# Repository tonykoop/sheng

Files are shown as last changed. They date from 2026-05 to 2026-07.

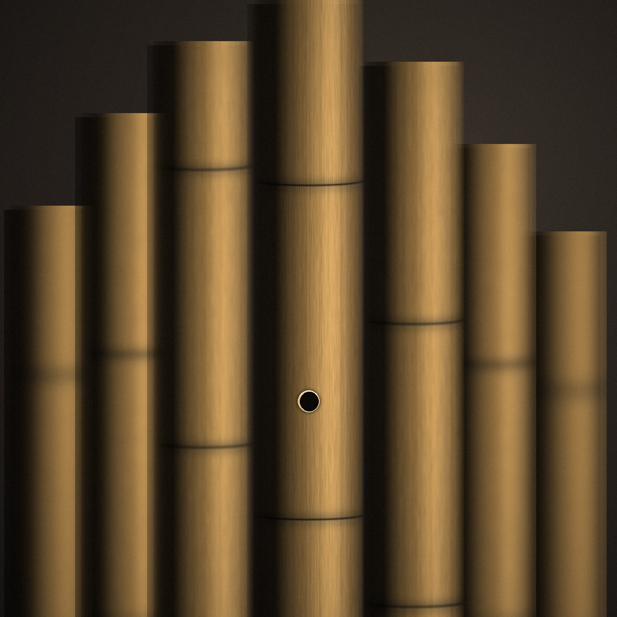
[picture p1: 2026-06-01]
images/macro/pipe-bundle-finger-holes.png

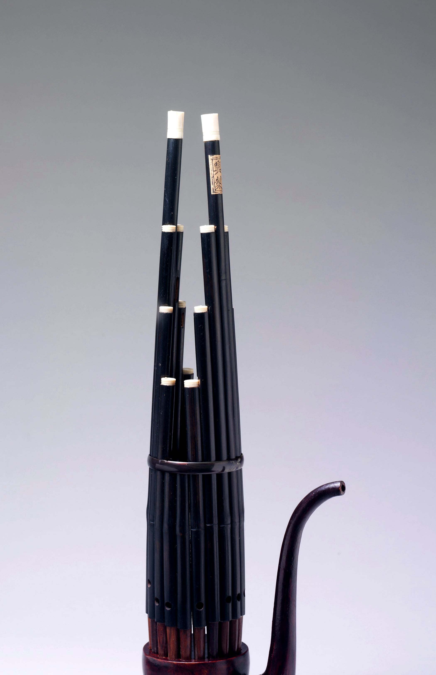
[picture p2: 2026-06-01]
images/hero-render.png

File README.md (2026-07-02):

# Sheng Mouth-Organ Family Packet

Generated: 2026-05-10

Status: L2 V5 build-packet candidate.

Current status: scaffold packet with two explicit architecture variants.
Fabrication authority: not build-ready.
Wolfram/runtime status: source-only; no Wolfram runtime validation has been run.

Studio explorer: open `explorer.html` for a generated packet showcase that
summarizes the design files, branch choices, validation gates, print packet,
Wolfram starter, and current public-release blockers.

This packet promotes the Round 8 sheng split from issue #153 and the
`tonykoop/sheng` issue #1 starter packet without choosing a premature winner.
The first workflow decision is the architecture branch:

- `traditional-side-branch/` keeps the traditional sheng-like side-branch reed
  model with both pipe ends open.
- `compact-control/` keeps the compact stopped-end prototype model with the
  reed acting as the closed end.

The two `family-spec.csv` files are intentionally separate. Do not merge them
into one universal sheng sheet unless measured reed coupon and single-pipe
control data prove that the same acoustic law and boundary condition apply to
both layouts.

## Quick Start

1. Read `architecture-choice.md` and pick exactly one branch for the next shop
   action.
2. Use `traditional-side-branch/family-spec.csv` when preserving a traditional
   sheng-like long-pipe geometry is the first design goal.
3. Use `compact-control/family-spec.csv` when proving a short, serviceable
   reed-pipe module is the first design goal.
4. Follow `free-reed-empirical-loop.md` and fill `p0-reed-coupon-log.csv`
   before claiming final reed pitch, onset pressure, pull-down, or cut-ready
   socket geometry.
5. Fill `p1-single-pipe-control-log.csv` and `windchest-geometry-plan.csv`
   before claiming coupled pipe pitch, chamber leakage status, or branch
   promotion beyond L2.
6. Check `safety-gates.csv` before any reed cutting, pressure test, leak test,
   or full-body layout.
7. Run the v4.4 acoustic-law validator on the chosen branch and the visual
   authority validator on `visual-output-register.csv`.

## File Map

| File | Purpose |
| --- | --- |
| `design.md` | Shared intent, scope, unknowns, and validation gates. |
| `architecture-choice.md` | First decision point: traditional side-branch vs compact control. |
| `traditional-side-branch/family-spec.csv` | Validator-aligned side-branch reed rows. |
| `compact-control/family-spec.csv` | Validator-aligned closed-open compact rows. |
| `p0-reed-coupon-log.csv` | Required reed coupon worksheet before full-family claims. |
| `p0-reed-coupon-data-sheet.csv` | Detailed P0 geometry and safety-source template for each coupon candidate. |
| `p1-single-pipe-control-log.csv` | Required coupled reed-pipe worksheet before branch promotion. |
| `free-reed-empirical-loop.md` | P0/P1 bench protocol with pull-down, onset, leak, and stop gates. |
| `windchest-geometry-plan.csv` | Chamber, gasket, inlet, pressure tap, and service-access planning table. |
| `safety-gates.csv` | Safety gates that must pass before cutting, pressure testing, or layout promotion. |
| `p0-onset-capture-form.csv` | P0 onset capture form for initial free-reed performance checks. |
| `p0-pull-down-capture-form.csv` | P0 pull-down capture form for target-pitch response checks. |
| `mouth-organ-dxf-checklist.csv` | Future DXF/CAD authority checklist. |
| `visual-output-register.csv` | V5 authority register for visuals, print packet, and concept support. |
| `cad/` | V5 CAD/provenance starter folder; not fabrication authority yet. |
| `wolfram/` | Source-only Wolfram model (`sheng-wolfram-model.wl`); not executed. |
| `evolution/` | Stage 0 evolution-pipeline intake (design intent, revision register, master manifest); Gate A not yet run. |
| `validation.csv` | Gates that move each branch from scaffold to prototype evidence. |

Both branch family specs carry `acoustic_law`, `end_condition`,
`reed_source_role`, and `unknown_requires_measurement` as explicit table
columns. The measurement gate is intentionally still open: no row claims final
reed dimensions, pull-down behavior, tuning measurements, or build-ready
windchest geometry.

## Round 33C Measurement Loop Evidence

Issue #8 adds single-pass bench-fill rows for both active P0 reed coupons and
one compact-control P1 single-pipe row. These rows record source role,
reed-alone pitch, pull-down/onset behavior, coupled pitch, response notes, and
leak/service observations, but they remain measurement-loop evidence only.
Repeat measurements and reviewed CAD/DXF or design-table authority are still
required before any branch promotion, production geometry, or public-readiness
claim.

## Validation Command

```bash
python3 /home/tony/.codex/skills/instrument-maker-v4/scripts/validate_acoustic_law.py \
  docs/build-packets/sheng-mouth-organ-family/traditional-side-branch/family-spec.csv

python3 /home/tony/.codex/skills/instrument-maker-v4/scripts/validate_acoustic_law.py \
  docs/build-packets/sheng-mouth-organ-family/compact-control/family-spec.csv
```

For this root-mode repo, run the same validator against the local files:

```bash
python3 /home/tony/.codex/skills/instrument-maker/scripts/validate_acoustic_law.py \
  traditional-side-branch/family-spec.csv

python3 /home/tony/.codex/skills/instrument-maker/scripts/validate_acoustic_law.py \
  compact-control/family-spec.csv

python3 /home/tony/.codex/skills/instrument-maker/scripts/validate_visual_authority.py \
  visual-output-register.csv
```

`Status: L2 V5 build-packet candidate` means the packet has the reviewable V5
surface and named blockers. It does not mean the sheng is build-ready.

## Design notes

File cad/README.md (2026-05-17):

# Sheng CAD Starter

Status: L2 V5 build-packet candidate support only.

This folder exists to anchor V5 CAD/provenance work without implying that
fabrication geometry is ready.

Current authority:

- `p0-p1-control-parameters.csv` is a design-table starter for review and
  measurement planning.
- `mcp-session-log.md` records the provenance and authority class of source
  artifacts.

Current non-authority:

- No DXF is cut-ready.
- No CAD body, windchest, reed window, socket map, or gasket land is
  fabrication authority.
- No Wolfram output has been executed or exported as runtime evidence.

Promotion beyond L2 requires measured P0 reed coupon data, measured P1
single-pipe control data, and reviewed DXF/CAD/design-table authority for the
chosen branch.

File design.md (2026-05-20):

# Sheng Traditional and Compact Prototype Packet

Generated: 2026-05-10

Issues addressed: tonykoop/instrument-maker#153; tonykoop/sheng#1.
V5 readiness: L2 V5 build-packet candidate, not L3/L4.
V5 standard source: tonykoop/instrument-maker#186.
MCP provenance source: tonykoop/instrument-maker#188.

## Scope

This packet publishes two sheng prototype branches as separate, validator-ready
packet variants:

- Traditional side-branch sheng: `acoustic_law=side_branch_reed`,
  `end_condition=both_ends_open`.
- Compact stopped-end prototype: `acoustic_law=closed_open`,
  `end_condition=one_end_closed_reed`.

Both branches are scaffold-level design packets. They are not build-ready CAD,
DXF, reed plates, or sourcing instructions. The pipe-length rows are first-pass
physics rows for branch comparison and validator alignment; reed behavior still
requires measured coupons and a single-pipe control before any full mouth-organ
layout can be treated as fabrication authority.

Each branch `family-spec.csv` now carries the Round 30 free-reed guard fields:
`acoustic_law`, `end_condition`, `reed_source_role`, and
`unknown_requires_measurement`. The two physics rows remain branch-comparison
scaffolds only; those explicit fields prevent a half-wave side-branch sheng row
from being confused with a compact closed-open control row, and they keep donor
reed or handmade reed behavior measurement-required until P0/P1 evidence is
logged.

## Architecture Decision First

Before drafting a body, windchest, or pipe rack, choose one branch in
`architecture-choice.md`.

Choose `traditional-side-branch` when the design objective is a traditional
sheng-like architecture: long pipes, reed in a side wall or socket area, and
both pipe ends acoustically open.

Choose `compact-control` when the design objective is a smaller experimental
module: a short pipe or chamber where the reed/windchest side creates the
closed boundary and the pipe speaks as a closed-open resonator.

Do not mix rows across branches in one fabrication drawing. The same target
note has different predicted pipe length in the two sheets because the boundary
condition is different.

## Fabrication Authority

Current fabrication authority: not build-ready.

Future authority must come from one of:

- Measured reed coupon data in `p0-reed-coupon-log.csv`.
- A single-pipe control drawing and measurement log.
- DXF/CAD files that name the governing branch, reed window, socket map, gasket
  land, service access, and pipe length source.
- A reviewed design table or measured template tied to the chosen branch.

Generated images, concept sketches, or visual-BOM plates may support review but
must not become dimensional authority for reed windows, pipe length, socket
location, or windchest geometry.

V5 packet authority is recorded in `visual-output-register.csv` and
`cad/mcp-session-log.md`. Current rows are source scaffolds and reference-only
outputs; none of them upgrades the packet beyond L2.

## P0/P1 Validation Plan

P0 is reed-alone evidence. Use `p0-reed-coupon-data-sheet.csv` to
record reed source, material, geometry, and fixture/safety pre-checks, and
`p0-reed-coupon-log.csv` to record reed-alone pitch, onset pressure, pull-down
target, blow/draw behavior, gap, window size, gasket leak status, and
measurement environment.

Collect free-reed behavior with dedicated capture forms before any P1 gate claim:
- `p0-pull-down-capture-form.csv`
- `p0-onset-capture-form.csv`

P1 is coupled reed-pipe evidence. Use `p1-single-pipe-control-log.csv` to record
one traditional side-branch single pipe and one compact closed-open control
before choosing a full-family body layout. P1 rows must cite their P0 coupon ID
and report coupled pitch error; blank P1 rows block any L3 or build-ready claim.

`free-reed-empirical-loop.md` is the bench protocol for both phases. It keeps
the test order explicit: source and inspect the reed, fixture it mechanically,
measure reed-alone pitch and onset, test pull-down behavior, then move the same
coupon into one single-pipe control only after safety and leakage gates pass.

`windchest-geometry-plan.csv` is a planning table, not fabrication geometry. It
names chamber volume, pressure path, gasket land, pressure tap, inlet, service
direction, and leak-test evidence that a future DXF or CAD file must carry.

Round 33C adds issue #8 measurement-loop rows for two P0 coupon candidates and
one compact-control P1 single-pipe control. Treat those rows as single-pass
bench evidence: useful for traceability and next-test planning, but still
repeat-required before branch promotion, production reed geometry, DXF/CAD
authority, or public-readiness claims.

## Open Measurements

| Measurement | Why It Matters | Status |
| --- | --- | --- |
| Reed-alone pitch for candidate sheng or donor reeds | Determines pull-down and whether target rows are realistic | measurement-required |
| Onset pressure and blow/draw behavior | Determines playability and windchest pressure range | measurement-required |
| Reed tongue gap and window geometry | Controls response, choking, and leakage | measurement-required |
| Gasket leak rate and service access | Controls repeatability and repairability | measurement-required |
| Single-pipe coupled pitch | Confirms the selected acoustic law before family layout | measurement-required |
| Windchest chamber leak behavior | Separates reed instability from fixture leakage | measurement-required |
| Safe pressure limit and reed retention | Prevents loose reed parts or overpressure during tests | measurement-required |

## Branch Promotion Gates

Move a branch from scaffold to prototype only when:

- Its `family-spec.csv` passes the v4.4 acoustic-law validator.
- At least one P0 reed coupon has measured reed-alone pitch, onset behavior,
  blow/draw behavior, leak status, and gap setting.
- One single-pipe control has a measured coupled pitch and notes whether it
  matches the declared acoustic law.
- The DXF/CAD checklist identifies branch, end condition, reed window, socket
  map, gasket land, windchest section, and service direction.
- The windchest plan records chamber volume, pressure tap, inlet, gasket land,
  leak-test method, leak status, and service access for the chosen branch.
- `safety-gates.csv` has no open stop conditions for the phase being promoted.
- `visual-output-register.csv` keeps generated or concept visuals out of the
  fabrication authority chain.
- `cad/mcp-session-log.md` names any external CAD/creative/runtime tool output
  and marks Wolfram work as source-only unless execution evidence exists.

## Safety and Scope Gates

- Do not claim current supplier availability, price, or lead time without a
  fresh purchase-time check.
- Do not publish private family/media/archive contents.
- Do not treat branch-comparison pipe lengths as cut-ready dimensions.
- Do not collapse the two branch family specs into one fake universal answer.

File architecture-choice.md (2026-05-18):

# Sheng Architecture Choice

Pick this before layout, CAD, DXF, sourcing, or full pipe count.

## Branch Comparison

| Branch | Use When | Acoustic Law | End Condition | Reed Source Role | Measurement Gate |
| --- | --- | --- | --- | --- | --- |
| `traditional-side-branch` | Preserve traditional sheng-like long pipes and side-branch reed coupling. | `side_branch_reed` | `both_ends_open` | `side_branch_free_reed_controls_pipe_coupling` | `unknown_requires_measurement` until P0 coupon and P1 side-branch pipe data exist. |
| `compact-control` | Prove a shorter, serviceable prototype module before committing to a traditional body. | `closed_open` | `one_end_closed_reed` | `free_reed_forms_closed_end_boundary` | `unknown_requires_measurement` until P0 coupon and P1 closed-open pipe data exist. |

## Traditional Side-Branch

Choose this branch when the primary value is architectural fidelity: long
visible pipes, a mouth-organ windchest, and a reed coupled through a side branch
or socket while both pipe ends remain acoustically open.

This branch uses half-wave pipe lengths in
`traditional-side-branch/family-spec.csv`. It is longer and less compact, but
it preserves the traditional boundary-condition claim that issue #153 asks us
to keep alive. The branch family spec names the reed role explicitly as
`side_branch_free_reed_controls_pipe_coupling` and keeps the measurement gate
open until P0/P1 evidence exists.

## Compact Control

Choose this branch when the primary value is fast empirical learning: a smaller
pipe module, easier reed service, and a clearer path to coupon-to-pipe
iteration.

This branch uses quarter-wave pipe lengths in
`compact-control/family-spec.csv`. It should not be described as traditional
sheng geometry; it is a compact prototype branch for proving reed, gasket,
socket, and windchest behavior. The branch family spec names the reed role
explicitly as `free_reed_forms_closed_end_boundary` and keeps the measurement
gate open until P0/P1 evidence exists.

## Shared Unknowns

Both branches need the same evidence before becoming build-ready:

- Reed-alone pitch.
- Coupled single-pipe pitch.
- Onset pressure.
- Pull-down cents.
- Blow/draw response.
- Leak status.
- Serviceable reed plate and gasket geometry.

If those measurements are missing, keep the branch label as scaffold or
prototype-planning, not production-ready.

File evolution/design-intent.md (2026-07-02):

# Design Intent — sheng rev A

- Master CAD: `cad/sheng.scad` (sha256: 695142b5c0cb4ef439ee537e12c7555de688d43d194713c1f1f25c70422e50e9), envelope-only pipe-rank master driven by `traditional-side-branch/family-spec.csv` (sha256: b47adbbefbd0d1ecc64dc0abc944b9fe332aedd9946f84c5a092b5edc4d9c62f) and `compact-control/family-spec.csv` (sha256: 59520daadd1f13a5ab16e09da1f7fe91ae88ca3afb64b3034391aa04bb44c8d8).
- Function: A free-reed mouth-organ (sheng), published as two comparable architecture branches rather than one premature winner (`architecture-choice.md`). `traditional-side-branch` preserves traditional sheng-like long pipes with the reed coupled through a side branch or socket while both pipe ends stay acoustically open (`acoustic_law=side_branch_reed`, `end_condition=both_ends_open`, half-wave pipe law). `compact-control` is a smaller experimental module where the reed/windchest side forms the closed boundary and the pipe speaks as a closed-open resonator (`acoustic_law=closed_open`, `end_condition=one_end_closed_reed`, quarter-wave pipe law). Both branches share the same eight-note rank (D4-E4-G4-A4-C5-D5-E5-G5) for direct comparison.
- Environment: bench/shop prototype; reed behavior (onset pressure, pull-down, blow/draw) is pressure- and leak-sensitive, so P0 (reed-alone) and P1 (single-pipe coupled) bench evidence must precede any full-family or windchest claim (`free-reed-empirical-loop.md`).
- Target qty: 1 (prototype). Deadline: TBD. Budget/unit ceiling: TBD.

## Critical dimensions (carry tolerances)

| Feature | Nominal | Tolerance | Why critical | Source |
| --- | --- | --- | --- | --- |
| Traditional-branch pipe rank lengths (D4-G5) | 575.9 / 512.2 / 429.4 / 381.6 / 319.6 / 283.9 / 252.0 / 210.6 mm | verify against measured coupled pitch (P1) | half-wave pipe length sets pitch under `side_branch_reed` law | traditional-side-branch/family-spec.csv `predicted_L_geom_mm` (physics_derived, analysis_only) |
| Compact-branch pipe rank lengths (D4-G5) | 287.9 / 256.1 / 214.7 / 190.8 / 159.8 / 141.9 / 126.0 / 105.3 mm | verify against measured coupled pitch (P1) | quarter-wave pipe length sets pitch under `closed_open` law | compact-control/family-spec.csv `predicted_L_geom_mm` (physics_derived, analysis_only) |
| Reed window size, tongue gap | TBD | measurement_required | controls response, choking, leakage; directly governs whether pull-down targets are realistic | cad/p0-p1-control-parameters.csv CAD-P0-001 / CAD-P0-002; `unknown_requires_measurement` — reed gate stays OPEN |
| Coupled pitch error (per branch) | TBD | measurement_required | confirms the declared acoustic law before any family layout | cad/p0-p1-control-parameters.csv CAD-P1-004; p1-single-pipe-control-log.csv |
| Windchest chamber volume, pressure tap, gasket land | TBD | measurement_required | separates reed instability from chamber leakage; sets serviceability | windchest-geometry-plan.csv; cad/p0-p1-control-parameters.csv CAD-WC-001..004 |
| Safe pressure limit | TBD (below onset overpressure) | measurement_required, safety-critical | prevents reed plate ejection / loose parts during testing | safety-gates.csv SAFE-003, SAFE-004 |

## Incidental (free for DFM)

- Windchest exterior styling, mouthpiece cosmetic shaping, pipe rank visual arrangement/fan angle, non-mating surface finish.

## Must-nots (DFM may never violate)

- Do not treat branch-comparison pipe lengths as cut-ready dimensions (design.md "Safety and Scope Gates"; risks.md "Fabrication").
- Do not collapse the two branch family-spec tables into one universal sheet — the boundary condition differs (`architecture-choice.md`).
- Do not infer reed window, tongue gap, or gasket land from concept images or generated visuals (cad/p0-p1-control-parameters.csv notes; safety-gates.csv SAFE-007).
- Do not exceed the logged safe pressure limit during onset/leak testing; reed plate must be mechanically retained before any pressure test (safety-gates.csv SAFE-002, SAFE-003; risks.md "Safety").
- Do not build a full mouth-organ windchest/body layout before one branch has measured coupled pitch, onset behavior, leak status, and service-access evidence (free-reed-empirical-loop.md P1 step 3).

## Material intent

- Preferred: bamboo or hardwood for traditional-side-branch long pipes; hardwood or printed test core for compact-control short control pipes (per branch `family-spec.csv` `material` column and bom.csv BOM-002/BOM-003).
- Acceptable subs: substitution_candidate status per bom.csv (BOM-002 through BOM-005); not yet coupon-tested.
- Forbidden: none recorded.

## Stage status

Stage 0 intake complete 2026-07-01. Gate A (Alpha shop compile) NOT yet run — no concessions logged, nothing presented as shippable. Reed/reed-table geometry, windchest chamber, and voicing remain unmeasured (`unknown_requires_measurement`) and out of scope for the current CAD master.

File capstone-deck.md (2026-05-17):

# Project Intent

Publish the sheng split from issue #153 and the `tonykoop/sheng` issue #1
starter packet as two explicit packet variants without forcing a premature
architecture winner.

# Branch Decision

The first decision is `traditional-side-branch` versus `compact-control`.

# Traditional Branch

Traditional side-branch rows use `side_branch_reed` with
`end_condition=both_ends_open`.

# Compact Branch

Compact control rows use `closed_open` with
`end_condition=one_end_closed_reed`.

# Family Spec

Each branch has its own `family-spec.csv`. The sheets must stay separate unless
measurements prove a shared acoustic model.

# Coupon Gate

The P0 reed coupon records reed-alone pitch, onset pressure, blow/draw behavior,
gap, window size, pull-down behavior, retention, and leak status.

# Single-Pipe Gate

One measured single-pipe control comes before any full mouth-organ body layout.

# Windchest Gate

Chamber volume, pressure tap, gasket land, inlet, service access, and leak
method stay in planning tables until measured evidence exists.

# Drawing Authority

Future DXF/CAD must name branch, reed window, socket map, gasket land,
windchest section, and service direction.

# Visual Authority

Generated images are concept or reference support only.

# Fabrication Status

Current status is scaffold. This packet is not build-ready.

# Risks

The primary risks are unmeasured reed behavior, chamber leakage, unsafe
pressure testing, and accidental branch mixing.

# Next Actions

Pick a branch, fill the P0 coupon and safety gates, build one single-pipe
control, run chamber leak checks, then revise the selected branch sheet with
measured evidence.

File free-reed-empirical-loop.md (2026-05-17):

# Free-Reed P0/P1 Empirical Loop

Status: L2 validation protocol. This is not build-ready fabrication geometry.

Use this loop before promoting either sheng branch beyond scaffold status. The
same coupon ID must follow the evidence chain from reed-alone testing into one
single-pipe control so branch behavior is traceable.

## P0 Reed Coupon

1. Source and identify the reed.
   Record `reed_source`, `source_status`, `source_provenance`, material, tongue
   length, tongue width, thickness, window length, window width, and frame land
   width in `p0-reed-coupon-log.csv`.
2. Inspect and make safe.
   Deburr all cut metal, confirm the reed plate is mechanically retained, and
   set a conservative pressure limit before blowing or using shop air.
3. Measure reed-alone pitch.
   Use a tuner or frequency logger while sweeping pressure slowly. Record the
   stable pitch range and the measurement environment.
4. Measure onset.
   Use a manometer or pressure sensor and record the first repeatable speaking
   pressure. If the reed starts only at unsafe pressure, stop and mark the
   coupon blocked.
5. Measure pull-down.
   Test whether the reed can be pulled toward the target note without choking,
   buzz instability, or unsafe pressure. Record target cents and measured cents.
6. Check leakage.
   Run a low-pressure hold on the coupon fixture. Leakage must be separated
   from reed instability before the coupon is allowed into P1.

## P1 Single-Pipe Control

1. Choose exactly one branch.
   Use `traditional-side-branch` for the side-branch reed model or
   `compact-control` for the closed-open control model.
2. Copy the P0 coupon ID into `p1-single-pipe-control-log.csv`.
   Do not create anonymous P1 rows.
3. Build only the single-pipe control.
   Full-family body layout waits until one branch has measured coupled pitch,
   onset behavior, leak status, and service-access evidence.
4. Record windchest geometry planning data.
   Fill `windchest-geometry-plan.csv` for chamber ID, chamber volume, inlet,
   pressure tap, gasket land, service direction, and leak-test method.
5. Measure coupled behavior.
   Record pitch, pitch error in cents, onset pressure, blow/draw behavior,
   chamber leak status, and service-access result.
6. Promote or revise.
   If coupled pitch or onset contradicts the declared acoustic law, keep the
   branch at L2 and revise the family-spec rows before any DXF/CAD authority.

## Stop Conditions

- Reed plate shifts, lifts, or ejects during pressure testing.
- Sharp reed tongue or burr remains after inspection.
- Onset requires pressure above the logged safe limit.
- Leak test cannot distinguish chamber leakage from reed response.
- The P1 row lacks a traceable P0 coupon ID.
- A drawing or generated image is being treated as dimensional authority before
  measured coupon and single-pipe data exist.

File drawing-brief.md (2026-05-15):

# Sheng Drawing Brief

Current drawing status: future authority.

## Required Drawings

| Drawing | Branch | Authority Level | Must Prove |
| --- | --- | --- | --- |
| P0 reed coupon DXF | both | future fabrication authority | Reed window, clamp line, tongue travel direction, gasket land |
| Traditional single-pipe control | traditional-side-branch | future fabrication authority | Side-branch reed placement and both-ends-open pipe condition |
| Compact single-pipe control | compact-control | future fabrication authority | Reed-side closed boundary and one open pipe end |
| Windchest section | both | future fabrication authority | Pressure path, service access, gasket compression, chamber assumption |
| Socket pitch map | selected branch only | future fabrication authority | Pipe ID, reed ID, note, acoustic law, length source |

## Non-Authority Visuals

Concept images and visual-BOM plates may communicate layout intent. They must
not set pipe length, reed window size, socket center, toolpath, or gasket
geometry.

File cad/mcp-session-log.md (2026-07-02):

# MCP Session Log

V5 provenance — aligned with `tonykoop/instrument-maker` V5 build-packet standard.

No MCP-connected CAD tool, image generator, or Wolfram runtime has produced
fabrication authority for this packet. All rows below are design-table derivations
or measurement-template work; none carry fabrication authority.

| session_id | tool | input_authority | outputs | role | authority_result | review_status | notes |
| --- | --- | --- | --- | --- | --- | --- | --- |
| 2026-05-17-design-table-v1 | design-table | acoustic-law formulas | traditional-side-branch/family-spec.csv | cad_authoring | reference_only | self_checked | Physics-derived branch rows; L2 only; not build-ready. |
| 2026-05-17-design-table-v1 | design-table | acoustic-law formulas | compact-control/family-spec.csv | cad_authoring | reference_only | self_checked | Physics-derived branch rows; L2 only; not build-ready. |
| 2026-05-17-design-table-v2 | design-table | p0-reed-coupon-log.csv | cad/p0-p1-control-parameters.csv | cad_authoring | reference_only | unreviewed | CAD parameter starter derived from coupon log; measurements TBD. |
| 2026-05-17-wolfram-v1 | wolfram | cad/p0-p1-control-parameters.csv | sheng-starter.wl | cad_authoring | reference_only | unreviewed | Source-only starter; not executed. |
| 2026-05-17-design-table-v3 | design-table | p1-single-pipe-control-log.csv | windchest-geometry-plan.csv | cad_authoring | reference_only | unreviewed | Windchest planning fields only; no fabrication geometry. |
| 2026-05-17-measurement-template-v1 | measurement-template | free-reed-empirical-loop.md | safety-gates.csv | cad_authoring | reference_only | unreviewed | Safety gate checklist; open until bench evidence exists. |
| 2026-05-18-round30-v1 | design-table | cad/mcp-session-log.md | traditional-side-branch/family-spec.csv; compact-control/family-spec.csv | cad_authoring | reference_only | self_checked | Added explicit reed_source_role and unknown_requires_measurement guard fields; still L2 only. |
| 2026-05-29-bob-r1 | measurement-template | p0-reed-coupon-log.csv; p1-single-pipe-control-log.csv | docs/p0-p1-measurement-summary.md | cad_authoring | reference_only | self_checked | Consolidated Round 33C evidence summary; no fabrication authority added. |
| fable-v5-refresh-2026-07-01 | claude-code (Fable 5) | traditional-side-branch/family-spec.csv; compact-control/family-spec.csv | visual-output-register.csv | packet_refresh | fabrication | self_checked | V5 refresh pass; tabular packet data reviewed against design table. `authority_result=fabrication` describes this register row (V5 bookkeeping authority) only — no instrument CSV in this repo carries fabrication authority yet; reed gates stay open per design.md ("Current fabrication authority: not build-ready"). |
| fable-v5-refresh-2026-07-01 | claude-code (Fable 5) | traditional-side-branch/family-spec.csv; compact-control/family-spec.csv | cad/sheng.scad | cad_authoring | pending_measurement | self_checked | New envelope-only OpenSCAD master: models ONLY the pipe-rank envelope (length + rank position) for both branches from the exact predicted_L_geom_mm rows in each family-spec.csv. Reed/reed-table geometry, windchest chamber, and voicing stay out of scope (unmeasured per p0-p1-control-parameters.csv). Render check: `openscad -o /tmp/sheng-check.stl cad/sheng.scad` exit 0. |
| fable-v5-refresh-2026-07-01 | claude-code (Fable 5) | cad/p0-p1-control-parameters.csv | wolfram/sheng-wolfram-model.wl | analysis_source | derived_preview | unreviewed | source-only; generated via generate_wolfram_packet.py, renamed from wolfram/instrument-model.wl; not executed (no --execute). |

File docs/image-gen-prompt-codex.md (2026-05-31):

# Image Generation Prompt

Concept image only; not fabrication authority. Do not include cut-ready dimensions, hole locations, reed-window dimensions, or toolpaths.

## Hero Prompt

Photorealistic 3/4 studio product visualization of a sheng prototype family packet represented as two real physical review objects: one traditional side-branch free-reed mouth-organ concept with long vertical pipes rising from a compact windchest, and one smaller compact-control single-pipe module with a short pipe, serviceable reed/windchest side, gasket land, and pressure-test fittings. Use bamboo or light wood pipes with subtle metal reed-plate details where visible, a clean unfinished prototype windchest, no ornate claims of traditional authenticity, clean neutral background, soft directional studio lighting, high detail, 50mm lens look.

## In-Context Prompt

Photorealistic bench-test scene for the sheng packet: a traditional side-branch pipe cluster and compact control module staged on an acoustician's workbench with reed coupons, gasket material, a small pressure gauge, leak-test notes, and removable pipe sockets. Natural workshop light, careful experimental mood, and visual separation between the two architecture branches so they are not mistaken for one universal design.

## Detail / Macro Prompt

Macro photorealistic close-up of the sheng signature mechanism as a prototype: a free-reed coupon seated near a pipe socket, gasket land, service-access screws, and the edge of a windchest, with a second pipe blurred behind it. Show the reed area as measurement-required and review-stage, with crisp material texture and no cut-ready reed-window geometry.

## Negative / Avoid

No text, no watermarks, no brand logos, no extra limbs, anatomically plausible hands if shown, no fake antique decoration, no impossible reed path, no merged branch geometry, no dimensions, no socket map, no toolpaths.

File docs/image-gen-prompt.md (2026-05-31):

# Image-Gen Prompts

Concept image only; not fabrication authority. Do not include cut-ready dimensions, hole locations, or toolpaths.

These prompts depict the envisioned sheng-style free-reed mouth organ described in
`design.md` and the visual/drawing briefs. They are concept visualizations and must
not set pipe length, reed-window size, socket centers, or windchest geometry. The
design carries two architecture branches (a traditional long-pipe side-branch sheng
with both pipe ends open, and a compact stopped-end control module); the hero and
in-context views show the recognizable bundled-pipe mouth-organ silhouette without
committing to measured pipe lengths or reed dimensions.

## Hero Prompt

A finished concept render of a sheng-style Chinese free-reed mouth organ standing
upright as a single hand-held instrument: a tight circular bundle of slender vertical
bamboo-toned pipes of varied lengths rising from a rounded cup-shaped windchest at the
base, with a short curved blow/draw mouthpiece tube projecting from the side of the
windchest. The pipes are gathered close like a sheaf, each a smooth turned tube with a
small fingering hole near its lower end where it enters the chest; the windchest reads
as a sealed metal-and-wood cup that bundles the pipe feet together. Materials and finish
implied by the design: warm honey-toned bamboo or pale hardwood pipes, a darker
lacquered or brushed-metal windchest cup, subtle visible reed sockets where pipes meet
the chest. Realistic hand-scale cues (an instrument about the height of a forearm),
clean neutral light-gray studio background, soft directional studio light from upper
left, 3/4 product-photography angle, ~50mm lens, shallow falloff, high detail,
photorealistic, no text labels.

## In-Context Prompt

The same bundled-pipe sheng concept staged on a maker's workbench in a quiet instrument
workshop: held lightly upright in two hands as if about to be played, the curved
mouthpiece near the player's lips, soft window daylight raking across the pipe bundle.
Background shows out-of-focus shop storytelling — a tuning bench, hand tools, a coil of
gasket cord, wood shavings — establishing this as a prototype free-reed mouth organ in
development. Natural light, shallow depth of field with the pipe bundle in crisp focus,
warm honest tones, concept visualization only, no text or callouts.

## Detail Prompt

A macro close-up at the base of the sheng where the slender pipes plug into the rounded
windchest cup: the signature free-reed sockets and pipe feet, showing how each pipe
seats into its gasketed socket with a small free reed implied at the closed boundary,
and a single fingering hole on the nearest pipe wall. Emphasize materials and textures —
fine bamboo grain, the seam where pipe meets the lacquered chest, a hint of brass reed
plate in shadow — under raking sidelight that brings out turning marks and the gasket
land. High detail, photorealistic, shallow depth of field, no measurements, no callouts.

## Negative / Avoid

No text, logos, watermarks, or fake maker marks; no dimension lines, hole-spacing
callouts, tuning numbers, or fabrication specifications; no impossible mechanisms or
free reeds drawn as fantasy parts; anatomically plausible hands if a player is shown.

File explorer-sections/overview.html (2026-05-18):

# 01 - OverviewSheng Mouth-Organ Family Packet

This explorer is the studio-facing index for the sheng free-reed mouth-organ packet. It brings the current design narrative, BOM, branch-specific family specs, validation gates, Wolfram source starter, print packet, and provenance notes into one review surface.

Packet status

The repo remains an L2 V5 build-packet candidate. It preserves two explicit architecture variants and keeps fabrication authority blocked until measured reed-coupon evidence, single-pipe control evidence, and reviewed DXF/CAD/design-table artifacts exist for the selected branch.

Round 30 free-reed guard

Both family specs now expose acoustic_law, end_condition, reed_source_role, and unknown_requires_measurement directly in the table. The traditional branch keeps the side-branch free reed as a pipe-coupling source; the compact branch keeps the free reed as the closed-end boundary. Both remain measurement-required until P0/P1 evidence exists.

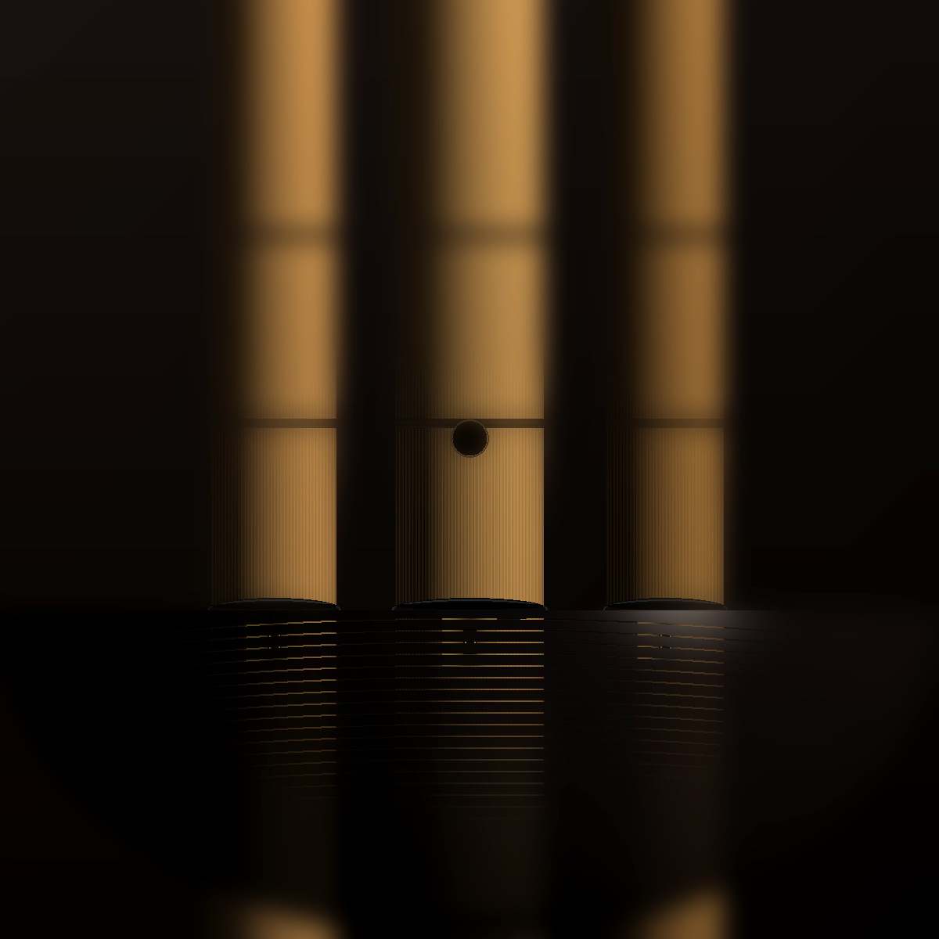
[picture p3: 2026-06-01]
images/macro/windchest-reed-sockets.png

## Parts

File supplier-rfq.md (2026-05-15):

# Sheng Prototype Supplier RFQ Notes

This is not a current quote request and does not claim price, availability, or
lead time.

## Quote Only After Measurements

Do not send an RFQ for a full branch until these rows exist:

- Reed-alone pitch.
- Onset pressure.
- Blow/draw behavior.
- Gap setting.
- Window size.
- Gasket leak status.
- One coupled single-pipe pitch.

## Candidate RFQ Fields

| Field | Required Detail |
| --- | --- |
| Branch | `traditional-side-branch` or `compact-control` |
| Reed material | Measured or specified alloy and thickness |
| Reed window | DXF/CAD authority file, not a concept image |
| Pipe material | Candidate material and bore/slot tolerance |
| Gasket | Material, compression stop, leak land |
| Service access | Direction and fastener access for reed replacement |

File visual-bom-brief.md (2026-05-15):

# Sheng Visual BOM Brief

Status: concept-support only.

## Visual Roles

| Visual | Role | Authority |
| --- | --- | --- |
| Branch comparison diagram | Explain side-branch vs compact-control decision | reference_only |
| Reed coupon photo or render | Show what to measure | reference_only until tied to measured coupon |
| Single-pipe control photo | Show test article | evidence_support after measurements are logged |
| Full sheng body concept | Communicate future direction | concept_only |

## Authority Rule

Any image generated by an AI model or drawn as a concept view must be labeled
`concept_only` or `reference_only`. Fabrication authority must remain DXF, CAD,
design table, measured template, or reviewed drawing.

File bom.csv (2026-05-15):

item_id | branch | item | qty | status | source_status | authority | notes
BOM-001 | both | free reed coupon blanks | 2 measurement sets | measurement-required | supplier_spec_unverified | not_fabrication_authority | Use only after reed-alone pitch and onset are measured
BOM-002 | traditional-side-branch | long pipe stock for side-branch control | 1 single-pipe test | measurement-required | substitution_candidate | not_fabrication_authority | Bamboo or hardwood candidate; final length comes after coupon validation
BOM-003 | compact-control | short control-pipe test core | 1 single-pipe test | measurement-required | substitution_candidate | not_fabrication_authority | Hardwood or printed test core for serviceable closed-open module
BOM-004 | both | gasket sheet and fasteners | 1 coupon set | measurement-required | supplier_spec_unverified | not_fabrication_authority | Choose after leak-land geometry is drawn
BOM-005 | both | windchest test block | 1 coupon fixture | measurement-required | substitution_candidate | not_fabrication_authority | Fixture for pressure path and service access experiments

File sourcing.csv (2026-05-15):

source_id | branch | component | source_status | search_terms | required_spec | notes
SRC-001 | both | sheng reed candidates | supplier_spec_unverified | sheng replacement reed brass free reed | reed material pitch window dimensions not yet measured | Verify at purchase time; no current price or availability claim
SRC-002 | compact-control | donor melodica reed candidates | supplier_spec_unverified | melodica reed plate donor replacement reeds | individual reed plate or salvageable donor reed | Use only as a coupon candidate until measured
SRC-003 | traditional-side-branch | bamboo or hardwood pipe stock | substitution_candidate | thin wall bamboo tube hardwood dowel bore blank | stable straight stock sized for single-pipe control | Stock dimensions are not authority for pipe length
SRC-004 | both | gasket material | supplier_spec_unverified | thin closed cell gasket sheet instrument reed plate | compressible leak-control gasket compatible with reed plate | Choose after gasket land and compression stop are drawn

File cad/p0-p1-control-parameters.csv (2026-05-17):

parameter_id | branch | phase | source_artifact | parameter | value | unit | status | authority | notes
CAD-P0-001 | both | P0 | p0-reed-coupon-log.csv | reed_window_size | TBD | mm | unknown_requires_measurement | measurement_required | Must come from measured reed or reviewed donor reed drawing
CAD-P0-002 | both | P0 | p0-reed-coupon-log.csv | tongue_gap | TBD | mm | unknown_requires_measurement | measurement_required | Do not infer from concept images
CAD-P0-003 | both | P0 | p0-reed-coupon-log.csv | gasket_leak_limit | TBD | TBD | unknown_requires_measurement | measurement_required | Define after coupon fixture leak test
CAD-P1-TRAD-001 | traditional-side-branch | P1 | traditional-side-branch/family-spec.csv | predicted_A4_pipe_length | 381.6 | mm | physics_derived | analysis_only | Half-wave side-branch row; not cut-ready until coupled pitch is measured
CAD-P1-COMP-001 | compact-control | P1 | compact-control/family-spec.csv | predicted_A4_pipe_length | 190.8 | mm | physics_derived | analysis_only | Quarter-wave compact row; not cut-ready until coupled pitch is measured
CAD-P1-004 | both | P1 | p1-single-pipe-control-log.csv | coupled_pitch_error | TBD | cents | unknown_requires_measurement | measurement_required | Required before branch promotion beyond L2
CAD-WC-001 | both | P1 | windchest-geometry-plan.csv | chamber_volume | TBD | ml | unknown_requires_measurement | measurement_required | Planning field only; must be measured or reviewed before CAD authority
CAD-WC-002 | both | P1 | windchest-geometry-plan.csv | pressure_tap_location | TBD | TBD | unknown_requires_measurement | measurement_required | Needed to separate onset pressure from chamber leakage
CAD-WC-003 | both | P1 | windchest-geometry-plan.csv | gasket_land_width | TBD | mm | unknown_requires_measurement | measurement_required | Do not infer from concept images or visual BOM
CAD-WC-004 | both | P1 | windchest-geometry-plan.csv | safe_pressure_limit | TBD | Pa | unknown_requires_measurement | measurement_required | Required safety gate before pressure tests

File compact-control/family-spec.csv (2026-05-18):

member_id | target_hz | target_note | architecture_branch | acoustic_law | end_condition | reed_source_role | unknown_requires_measurement | dimension_provenance | predicted_L_geom_mm | pipe_role | material | notes
SNG-COMP-D4 | 293.66 | D4 | compact-control | closed_open | one_end_closed_reed | free_reed_forms_closed_end_boundary | p0_reed_coupon_and_p1_single_pipe_required_before_fabrication | physics_derived | 287.9 | short_control_pipe | hardwood_or_printed_test_core | Quarter-wave compact branch; not traditional sheng geometry
SNG-COMP-E4 | 329.63 | E4 | compact-control | closed_open | one_end_closed_reed | free_reed_forms_closed_end_boundary | p0_reed_coupon_and_p1_single_pipe_required_before_fabrication | physics_derived | 256.1 | short_control_pipe | hardwood_or_printed_test_core | Quarter-wave compact branch; not traditional sheng geometry
SNG-COMP-G4 | 392.00 | G4 | compact-control | closed_open | one_end_closed_reed | free_reed_forms_closed_end_boundary | p0_reed_coupon_and_p1_single_pipe_required_before_fabrication | physics_derived | 214.7 | short_control_pipe | hardwood_or_printed_test_core | Quarter-wave compact branch; verify reed seat and gasket leak path
SNG-COMP-A4 | 440.00 | A4 | compact-control | closed_open | one_end_closed_reed | free_reed_forms_closed_end_boundary | p0_reed_coupon_and_p1_single_pipe_required_before_fabrication | physics_derived | 190.8 | short_control_pipe | hardwood_or_printed_test_core | A440 compact anchor candidate; coupon data required before layout
SNG-COMP-C5 | 523.25 | C5 | compact-control | closed_open | one_end_closed_reed | free_reed_forms_closed_end_boundary | p0_reed_coupon_and_p1_single_pipe_required_before_fabrication | physics_derived | 159.8 | short_control_pipe | hardwood_or_printed_test_core | Quarter-wave compact branch; not traditional sheng geometry
SNG-COMP-D5 | 587.33 | D5 | compact-control | closed_open | one_end_closed_reed | free_reed_forms_closed_end_boundary | p0_reed_coupon_and_p1_single_pipe_required_before_fabrication | physics_derived | 141.9 | short_control_pipe | hardwood_or_printed_test_core | Quarter-wave compact branch; verify coupled pitch before scaling
SNG-COMP-E5 | 659.25 | E5 | compact-control | closed_open | one_end_closed_reed | free_reed_forms_closed_end_boundary | p0_reed_coupon_and_p1_single_pipe_required_before_fabrication | physics_derived | 126.0 | short_control_pipe | hardwood_or_printed_test_core | Quarter-wave compact branch; verify coupled pitch before scaling
SNG-COMP-G5 | 784.00 | G5 | compact-control | closed_open | one_end_closed_reed | free_reed_forms_closed_end_boundary | p0_reed_coupon_and_p1_single_pipe_required_before_fabrication | physics_derived | 105.3 | short_control_pipe | hardwood_or_printed_test_core | High compact row; may be too sensitive to reed setup and machining tolerance

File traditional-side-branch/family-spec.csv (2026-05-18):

member_id | target_hz | target_note | architecture_branch | acoustic_law | end_condition | reed_source_role | unknown_requires_measurement | dimension_provenance | predicted_L_geom_mm | pipe_role | material | notes
SNG-TRAD-D4 | 293.66 | D4 | traditional-side-branch | side_branch_reed | both_ends_open | side_branch_free_reed_controls_pipe_coupling | p0_reed_coupon_and_p1_single_pipe_required_before_fabrication | physics_derived | 575.9 | long_pipe | bamboo_or_hardwood | Half-wave side-branch row; verify with measured reed coupon and single-pipe control
SNG-TRAD-E4 | 329.63 | E4 | traditional-side-branch | side_branch_reed | both_ends_open | side_branch_free_reed_controls_pipe_coupling | p0_reed_coupon_and_p1_single_pipe_required_before_fabrication | physics_derived | 512.2 | long_pipe | bamboo_or_hardwood | Half-wave side-branch row; verify with measured reed coupon and single-pipe control
SNG-TRAD-G4 | 392.00 | G4 | traditional-side-branch | side_branch_reed | both_ends_open | side_branch_free_reed_controls_pipe_coupling | p0_reed_coupon_and_p1_single_pipe_required_before_fabrication | physics_derived | 429.4 | long_pipe | bamboo_or_hardwood | Half-wave side-branch row; verify with measured reed coupon and single-pipe control
SNG-TRAD-A4 | 440.00 | A4 | traditional-side-branch | side_branch_reed | both_ends_open | side_branch_free_reed_controls_pipe_coupling | p0_reed_coupon_and_p1_single_pipe_required_before_fabrication | physics_derived | 381.6 | long_pipe | bamboo_or_hardwood | A440 anchor candidate; not cut-ready until coupled pitch is measured
SNG-TRAD-C5 | 523.25 | C5 | traditional-side-branch | side_branch_reed | both_ends_open | side_branch_free_reed_controls_pipe_coupling | p0_reed_coupon_and_p1_single_pipe_required_before_fabrication | physics_derived | 319.6 | long_pipe | bamboo_or_hardwood | Half-wave side-branch row; verify with measured reed coupon and single-pipe control
SNG-TRAD-D5 | 587.33 | D5 | traditional-side-branch | side_branch_reed | both_ends_open | side_branch_free_reed_controls_pipe_coupling | p0_reed_coupon_and_p1_single_pipe_required_before_fabrication | physics_derived | 283.9 | long_pipe | bamboo_or_hardwood | Half-wave side-branch row; verify with measured reed coupon and single-pipe control
SNG-TRAD-E5 | 659.25 | E5 | traditional-side-branch | side_branch_reed | both_ends_open | side_branch_free_reed_controls_pipe_coupling | p0_reed_coupon_and_p1_single_pipe_required_before_fabrication | physics_derived | 252.0 | long_pipe | bamboo_or_hardwood | Half-wave side-branch row; verify with measured reed coupon and single-pipe control
SNG-TRAD-G5 | 784.00 | G5 | traditional-side-branch | side_branch_reed | both_ends_open | side_branch_free_reed_controls_pipe_coupling | p0_reed_coupon_and_p1_single_pipe_required_before_fabrication | physics_derived | 210.6 | long_pipe | bamboo_or_hardwood | High-row half-wave side-branch candidate; verify reed response before family expansion

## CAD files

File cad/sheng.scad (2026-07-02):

// Sheng pipe-rank ENVELOPE master — branch comparison, both architectures.
//
// Authority: pending_measurement. NOT fabrication authority until reviewed.
//
// SCOPE: this file models ONLY the pipe-rank envelope (pipe length + rank
// position) for each architecture branch, using the exact predicted_L_geom_mm
// values already published in the branch family-spec.csv tables. It is a
// branch-comparison / packaging-envelope aid, nothing more.
//
// OUT OF SCOPE (do NOT add without measured evidence):
//   - Reed/reed-table geometry (window, tongue, gap, frame land).
//   - Windchest chamber, socket map, gasket land, pressure path, service
//     access.
//   - Voicing, onset pressure, pull-down, blow/draw behavior.
// All of the above are unknown_requires_measurement per
// cad/p0-p1-control-parameters.csv (reed gates stay OPEN — legitimately
// unmeasured). This master must be hand-refined only after P0 reed-coupon and
// P1 single-pipe control-log measurements exist (see
// free-reed-empirical-loop.md, p0-reed-coupon-log.csv,
// p1-single-pipe-control-log.csv).
//
// Dimension sources (do not edit length values without updating the source
// table row):
//   - traditional_lengths_mm[] <- traditional-side-branch/family-spec.csv
//     column predicted_L_geom_mm (dimension_provenance=physics_derived,
//     acoustic_law=side_branch_reed, end_condition=both_ends_open, half-wave
//     row per architecture-choice.md).
//   - compact_lengths_mm[] <- compact-control/family-spec.csv column
//     predicted_L_geom_mm (dimension_provenance=physics_derived,
//     acoustic_law=closed_open, end_condition=one_end_closed_reed,
//     quarter-wave row per architecture-choice.md).
//   - Both tables are branch-comparison scaffolds only (design.md "Scope");
//     rows are physics_derived / analysis_only, not cut-ready
//     (cad/p0-p1-control-parameters.csv rows CAD-P1-TRAD-001 /
//     CAD-P1-COMP-001).
//   - pipe_dia_mm below is a visualization_placeholder / prototype_assumption
//     ONLY — real bore/reed-window geometry is unknown_requires_measurement
//     (CAD-P0-001, CAD-P0-002). It carries no acoustic or fabrication
//     authority; it exists only so the rank envelope renders as solid stock.
//
// Units: millimeters.

/* [Branch selection] */
// 0 = traditional-side-branch only, 1 = compact-control only,
// 2 = both, side-by-side for comparison (default; matches packet's stated
// purpose of publishing both branches as separate, comparable variants).
branch_display = 2;

/* [Pipe-rank note table — shared note set across both branches] */
note_names = ["D4", "E4", "G4", "A4", "C5", "D5", "E5", "G5"];
target_hz  = [293.66, 329.63, 392.00, 440.00, 523.25, 587.33, 659.25, 784.00];

// traditional-side-branch/family-spec.csv, predicted_L_geom_mm column,
// rows SNG-TRAD-D4 .. SNG-TRAD-G5 (half-wave, side_branch_reed).
traditional_lengths_mm = [575.9, 512.2, 429.4, 381.6, 319.6, 283.9, 252.0, 210.6];

// compact-control/family-spec.csv, predicted_L_geom_mm column,
// rows SNG-COMP-D4 .. SNG-COMP-G5 (quarter-wave, closed_open).
compact_lengths_mm = [287.9, 256.1, 214.7, 190.8, 159.8, 141.9, 126.0, 105.3];

/* [Envelope-only cross-section — visualization placeholder, not a bore spec] */
pipe_dia_mm     = 10;  // prototype_assumption; NOT reed window / bore geometry
pipe_gap_mm     = 6;   // prototype_assumption; rank spacing clearance only
branch_offset_mm = 250; // separation between the two comparison ranks (display only)

// ---------------------------------------------------------------------------
// Derived geometry (equation-driven placement; lengths themselves are the
// published table values above, not derived here)
// ---------------------------------------------------------------------------

pitch_mm = pipe_dia_mm + pipe_gap_mm;

function rank_x(i) = i * pitch_mm;

// One envelope pipe: a plain round blank of the table length, standing on
// the rank baseline (z=0). No reed window, bore taper, or socket cut — those
// are out of scope per header.
module envelope_pipe(length_mm) {
  cylinder(h = length_mm, d = pipe_dia_mm, $fn = 32);
}

module pipe_rank(lengths_mm) {
  for (i = [0 : len(lengths_mm) - 1])
    translate([rank_x(i), 0, 0])
      envelope_pipe(lengths_mm[i]);
}

module traditional_side_branch_rank() {
  // side_branch_reed, both_ends_open — half-wave rank.
  pipe_rank(traditional_lengths_mm);
}

module compact_control_rank() {
  // closed_open, one_end_closed_reed — quarter-wave rank.
  pipe_rank(compact_lengths_mm);
}

module sheng_envelope_assembly() {
  if (branch_display == 0) {
    traditional_side_branch_rank();
  } else if (branch_display == 1) {
    compact_control_rank();
  } else {
    // Both branches, offset along Y so neither rank overlaps the other.
    // This is a display convenience only — it does not imply a shared
    // windchest or fabrication layout between the two branches
    // (design.md: "Do not mix rows across branches in one fabrication
    // drawing.").
    translate([0, 0, 0])
      traditional_side_branch_rank();
    translate([0, branch_offset_mm, 0])
      compact_control_rank();
  }
}

sheng_envelope_assembly();

// Echo the rank tables so `openscad` doubles as a length-table sanity check
// against the source family-spec.csv files.
for (i = [0 : len(note_names) - 1])
  echo(str("traditional_", note_names[i], "_L_geom_mm=", traditional_lengths_mm[i]));
for (i = [0 : len(note_names) - 1])
  echo(str("compact_", note_names[i], "_L_geom_mm=", compact_lengths_mm[i]));

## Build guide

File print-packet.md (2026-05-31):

# Sheng Mouth-Organ Family Print Packet

Generated: 2026-05-10

Status: L2 V5 build-packet candidate, not build-ready.

## Issue

This packet addresses tonykoop/instrument-maker#153 and tonykoop/sheng#1 by
promoting both Round 8 sheng branches as explicit variants:

- `traditional-side-branch/family-spec.csv`
- `compact-control/family-spec.csv`

## First Decision

Read `architecture-choice.md` and select one branch before layout.

## Validation

Run the v4.4 acoustic-law validator on the selected branch. Both branch sheets
are meant to pass the validator while preserving different boundary conditions.

Run the visual authority validator on `visual-output-register.csv`. This print
packet is reference-only layout support, not fabrication authority.

Use `free-reed-empirical-loop.md`, `windchest-geometry-plan.csv`, and
`safety-gates.csv` before any P0/P1 bench work. These files are planning and
measurement templates, not cut geometry.

## Fabrication Authority

No file in this packet is cut-ready authority yet. Future authority must come
from measured coupon data, single-pipe control evidence, and DXF/CAD or design
tables that name the selected branch.

`cad/mcp-session-log.md` records V5 provenance for design-table and Wolfram
source artifacts. Wolfram work is source-only unless runtime evidence is added.

## File Map

- `README.md`
- `design.md`
- `architecture-choice.md`
- `traditional-side-branch/family-spec.csv`
- `compact-control/family-spec.csv`
- `p0-reed-coupon-log.csv`
- `p1-single-pipe-control-log.csv`
- `free-reed-empirical-loop.md`
- `windchest-geometry-plan.csv`
- `safety-gates.csv`
- `mouth-organ-dxf-checklist.csv`
- `visual-output-register.csv`
- `cad/mcp-session-log.md`
- `cad/p0-p1-control-parameters.csv`
- `validation.csv`
- `bom.csv`
- `sourcing.csv`
- `cut-list.csv`
- `assembly-manual.md`
- `supplier-rfq.md`
- `drawing-brief.md`
- `visual-bom-brief.md`
- `risks.md`
- `sheng-starter.wl`

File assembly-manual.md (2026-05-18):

# Sheng Scaffold Assembly Manual

Status: scaffold-only sequence. Not build-ready.

## Branch Setup

1. Read `architecture-choice.md`.
2. Select either `traditional-side-branch` or `compact-control`.
3. Keep the selected branch's `family-spec.csv` beside the bench notes.
4. Do not mix branch rows in one control article.

## P0 Reed Coupon

1. Make or fixture one reed coupon.
2. Record reed source, material, gap setting, and window size in
   `p0-reed-coupon-log.csv`.
3. Measure reed-alone pitch.
4. Measure onset pressure and blow/draw response.
5. Record gasket leak status.
6. Capture pull-down and onset details in
   `p0-pull-down-capture-form.csv` and `p0-onset-capture-form.csv`.

## Single-Pipe Control

1. Pick one target row from the selected branch.
2. Build one pipe only.
3. Measure coupled pitch at a logged temperature and humidity.
4. Compare the result to the declared `acoustic_law` and `end_condition`.
5. Update the branch row or mark it `measurement_required` if the law does not
   match measured behavior.

## Stop Point

Stop before full sheng body layout until the coupon and single-pipe gates in
`validation.csv` are complete.

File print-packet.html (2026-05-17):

# Sheng Mouth-Organ Family Packet

Status: L2 V5 build-packet candidate, not build-ready.

## Branches

- traditional-side-branch: side_branch_reed, both_ends_open.
- compact-control: closed_open, one_end_closed_reed.

## Authority

Fabrication authority must come from measured coupon data, single-pipe control evidence, and branch-labeled DXF/CAD or design tables.

## V5 Evidence

- Visual authority: visual-output-register.csv.
- MCP/tool provenance: cad/mcp-session-log.md.
- P0 coupon evidence: p0-reed-coupon-log.csv.
- P1 coupled-pipe evidence: p1-single-pipe-control-log.csv.
- P0/P1 protocol: free-reed-empirical-loop.md.
- Windchest planning: windchest-geometry-plan.csv.
- Safety gates: safety-gates.csv.
- Wolfram status: source-only; no runtime validation has been run.

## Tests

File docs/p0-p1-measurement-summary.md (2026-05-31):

# Sheng P0/P1 Measurement Evidence Summary

Status: L2 measurement-loop evidence. Not build-ready.

This document consolidates the Round 33C single-pass bench evidence for the sheng
packet so future reviewers can read one file to understand what was captured, what
still needs to be repeated, and what blocks promotion.

All frequency and pitch values below are **model estimates or single-pass
bench-fill rows**. Repeat measurements and reviewed CAD/DXF or design-table
authority are required before any branch promotion, production geometry, or
public-readiness claim.

## Architecture Gate (open)

The architecture branch has not been selected. Two branches remain active:

| Branch | Acoustic law | End condition | P1 status |
| --- | --- | --- | --- |
| `traditional-side-branch/` | side_branch_reed | both_ends_open | BLOCKED — reed plate lift risk; repeat P0 first |
| `compact-control/` | closed_open | one_end_closed_reed | single-pass P1 captured; repeat before promotion |

Do not merge or unify the two `family-spec.csv` files until measured reed coupon
and single-pipe control data prove that the same acoustic law and boundary
condition apply to both layouts.

## P0 Reed Coupon Evidence (Round 33C)

Two P0 coupon rows recorded in `p0-reed-coupon-log.csv`. Single-pass bench fill;
not production reed geometry.

| Coupon ID | Branch | Reed material | Reed-alone pitch | Pull-down | Onset pressure Pa | Leak status | Safe pressure Pa | Next action |
| --- | --- | --- | --- | --- | --- | --- | --- | --- |
| SNG-P0-TRAD-001 | traditional-side-branch | brass, 0.18 mm | 438.7 Hz (A4 flat) | −18 cents measured vs −10 to −30 target | 245 | low-pressure-hold pass | 700 | Repeat before side-branch P1 fixture |
| SNG-P0-COMP-001 | compact-control | brass, 0.16 mm | 441.8 Hz (A4 sharp) | −12 cents measured | 220 | low-pressure-hold pass | 650 | Use as traceable P0 for compact P1; repeat before branch promotion |

Evidence level: `partial_evidence` per `validation.csv` VAL-004, VAL-016, VAL-017, VAL-018.
These rows were bench-filled from the Round 33C worksheet. Supplier lot for the
traditional-side-branch candidate and final source for the compact-control donor
melodica reed have not been verified.

## P1 Single-Pipe Control Evidence (Round 33C)

Two P1 control rows recorded in `p1-single-pipe-control-log.csv`.

| Control ID | Branch | P0 coupon | Coupled pitch Hz | Pitch error cents | Leak status | Service access | Status |
| --- | --- | --- | --- | --- | --- | --- | --- |
| SNG-P1-TRAD-001 | traditional-side-branch | SNG-P0-TRAD-001 | — | — | unknown | — | BLOCKED — reed plate lifts outward; cannot run until retention and leak evidence from P0 repeat |
| SNG-P1-COMP-001 | compact-control | SNG-P0-COMP-001 | 438.9 Hz | −4.3 cents | below visible bubble threshold (pass) | reed removed without gasket damage | single_pass_measurement_loop_evidence; repeat with measured chamber leak rate |

Evidence level: `partial_evidence` per `validation.csv` VAL-006, VAL-013, VAL-014.
The compact branch P1 row is the only measured coupled-pitch evidence in this packet.
It must be repeated with a quantified chamber leak rate before branch promotion.

## Open Stop Conditions (safety-gates.csv)

Check `safety-gates.csv` before any:
- Reed cutting or tongue grinding
- Pressure testing above the logged safe limit
- Full-body layout or branch-promotion decision

The traditional-side-branch P1 is explicitly blocked until the reed plate
lift/retention stop condition is resolved.

## Gates Still Open

| Gate ID | Gate | Blocking reason |
| --- | --- | --- |
| VAL-001 | architecture_choice | Neither branch selected for next layout action |
| VAL-005 | p1_single_pipe_control (traditional) | BLOCKED — repeat P0 first |
| VAL-007 | dxf_authority | No DXF/CAD until coupon + single-pipe evidence complete |
| VAL-008 | visual_authority | visual-output-register.csv validator not yet run |
| VAL-009 | mcp_provenance | No MCP CAD session has produced fabrication artifacts |
| VAL-010 | wolfram_runtime | sheng-starter.wl is source-only; not executed |
| VAL-015 | safety_gates | Open stop conditions remain before P0/P1 bench work |

## Next Actions

1. Resolve the traditional-side-branch P0 retention stop condition before any P1
   attempt on that branch.
2. Repeat the compact-control P1 with a measured chamber leak rate (quantified
   ml/s or Pa/s decay, not just visual bubble threshold).
3. Select one branch as the next shop action target per `architecture-choice.md`.
4. Run `validate_visual_authority.py visual-output-register.csv` and resolve any
   remaining authority issues.
5. When DXF/CAD is needed: do not create it until P0 and P1 evidence for the chosen
   branch is complete and validated.

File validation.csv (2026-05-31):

gate_id | branch | gate | required_evidence | status | next_action
VAL-001 | both | architecture_choice | architecture-choice.md branch selected before layout | open | Pick one branch for the next drawing or coupon
VAL-002 | traditional-side-branch | acoustic_law_validator | traditional-side-branch/family-spec.csv passes validate_acoustic_law.py | open | Run validator after any row edit
VAL-003 | compact-control | acoustic_law_validator | compact-control/family-spec.csv passes validate_acoustic_law.py | open | Run validator after any row edit
VAL-004 | both | p0_reed_coupon | reed-alone pitch onset pressure blow/draw behavior gap and leak status recorded | partial_evidence | Round 33C added single-pass P0 rows; repeat before promotion or CAD authority
VAL-005 | traditional-side-branch | p1_single_pipe_control | one measured side-branch pipe confirms or revises side_branch_reed row and cites P0 coupon ID | open | Build one coupon-to-pipe test before full sheng layout
VAL-006 | compact-control | p1_single_pipe_control | one measured closed-open pipe confirms or revises compact row and cites P0 coupon ID | partial_evidence | Round 33C added one traceable compact P1 row; repeat with measured leak rate before compact branch promotion
VAL-007 | both | dxf_authority | mouth-organ-dxf-checklist.csv completed for chosen branch | open | Create DXF/CAD only after coupon and single-pipe evidence
VAL-008 | both | visual_authority | visual-output-register.csv passes validate_visual_authority.py and generated images are marked concept_only or reference_only | open | Keep CAD DXF design table or measured template as fabrication authority
VAL-009 | both | mcp_provenance | cad/mcp-session-log.md records design-table/Wolfram/visual tool outputs and authority | open | Update the log whenever a CAD creative or runtime tool changes an artifact
VAL-010 | both | wolfram_runtime | sheng-starter.wl has execution log and committed outputs before runtime claims | open | Run Wolfram only when available and record command/date/output hashes
VAL-011 | both | v5_readiness | README status remains L2 until P0 P1 CAD/DXF and authority gates pass | open | Do not claim L3 or build-ready until evidence exists
VAL-012 | both | p0_pull_down_onset | p0-reed-coupon-log.csv records pull-down target measured pull-down onset method onset pressure and safe pressure limit | partial_evidence | Round 33C added single-pass pull-down and onset values; repeat before fabrication authority
VAL-013 | both | windchest_geometry_plan | windchest-geometry-plan.csv records chamber volume pressure path inlet pressure tap gasket land service direction and authority status | partial_evidence | Compact P1 row now has single-pass planning values; keep authority planning-only
VAL-014 | both | chamber_leakage | p1-single-pipe-control-log.csv records chamber leak method rate leak status and service access result | partial_evidence | Compact P1 row records visible-threshold leak result; repeat with quantified leak rate
VAL-015 | both | safety_gates | safety-gates.csv has phase gates checked before reed cutting pressure testing or branch promotion | open | Resolve open stop conditions before P0 or P1 bench work
VAL-016 | both | p0_reed_coupon_data_sheet | p0-reed-coupon-data-sheet.csv has one completed entry per active branch candidate | partial_evidence | Round 33C bench-filled both active branch candidates as repeat-required evidence
VAL-017 | both | p0_pull_down_capture | p0-pull-down-capture-form.csv has pull-down target pressure sweep behavior and choke safety check | partial_evidence | Round 33C added one pull-down capture per active branch candidate; repeat before promotion
VAL-018 | both | p0_onset_capture | p0-onset-capture-form.csv has onset pressure and blow/draw notes for the selected P0 coupon | partial_evidence | Round 33C added one onset capture per active branch candidate; repeat before promotion

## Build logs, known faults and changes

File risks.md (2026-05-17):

# Risks

## Acoustic

- Free-reed pitch may not pull down to the target pipe note.
- The same reed may behave differently in side-branch and closed-open layouts.
- Leakage can make both branches appear falsely unstable.
- Chamber leakage can masquerade as reed pull-down failure or poor onset.

Mitigation: start with P0 coupon measurements, then one single-pipe control.

## Fabrication

- Reed windows and gasket lands are small enough that rough sketches can become
  misleading quickly.
- Bamboo, hardwood, printed cores, and ceramic shells will not share the same
  tolerances or service behavior.

Mitigation: keep the first acoustic core removable and delay full-body CAD.

## Safety

- Sharp reed tongues and small metal edges need deburring and eye protection
  during tuning.
- Blowing high pressure into a leaky fixture can eject loose reed parts.
- Unregulated shop air can exceed safe onset-test pressure before the reed
  speaks.

Mitigation: fixture the reed plate mechanically, deburr before handling, set a
safe pressure limit, and test at low pressure first.

## Scope

- A compact prototype can be useful without being traditional.
- A traditional side-branch layout can be valid without being compact.

Mitigation: keep branch labels visible in every file and drawing.

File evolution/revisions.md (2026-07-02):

# Revision Register — sheng

| Rev | Date | Parent | Delta | Downstream artifacts invalidated |
| --- | --- | --- | --- | --- |
| A | 2026-07-01 | — | Stage 0 intake of current masters (cad/sheng.scad, envelope-only pipe-rank master for both branches + traditional-side-branch/family-spec.csv + compact-control/family-spec.csv + wolfram/sheng-wolfram-model.wl). | none (no alpha/beta/production artifacts exist yet) |

Stage 0 only. Gate A has not been run; no Alpha compiles, vendor quotes, or production lock exist for this product. Reed geometry, windchest chamber, and voicing remain unmeasured (`unknown_requires_measurement`) for both branches; downstream evolution work must not treat the current pipe-rank envelope as fabrication authority.

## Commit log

2026-05-15 Add sheng mouth-organ family packet
    [bom.csv, cut-list.csv, family-spec.csv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]
2026-05-17 Add V5 sheng packet provenance
    [p0-p1-control-parameters.csv, p1-single-pipe-control-log.csv, validation.csv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]
2026-05-17 Add sheng reed loop gates
    [mouth-organ-dxf-checklist.csv, p0-p1-control-parameters.csv, p0-reed-coupon-log.csv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]
2026-05-18 Add A3 sheng P0 reed coupon and capture form artifacts (#5)
    [p0-onset-capture-form.csv, p0-pull-down-capture-form.csv, p0-reed-coupon-data-sheet.csv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]
2026-05-18 Add Round 30 sheng free-reed guard fields (#7)
    [family-spec.csv]
2026-05-20 Add issue 8 sheng reed measurement loop rows (#9)
    [p0-onset-capture-form.csv, p0-pull-down-capture-form.csv, p0-reed-coupon-data-sheet.csv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]
2026-05-29 Add P0/P1 measurement summary and align mcp-session-log to V5 standard (Refs #8) (#10)
    Adds docs/p0-p1-measurement-summary.md consolidating Round 33C evidence:
    two P0 coupon rows (partial_evidence), compact-control P1 row (single-pass),
    traditional-side-branch P1 blocked on reed-plate lift stop condition.
    Updates cad/mcp-session-log.md to V5-standard columns.
    No fabrication authority added; packet remains L2 V5 build-packet candidate.
2026-05-31 wolfram-rename(sheng): unique {slug}-starter.wl + dedupe + ref fixes (cloud-sync naming) (#13)
    [validation.csv]
2026-05-31 Add image-gen concept prompt; wire explorer images
2026-06-21 Wire 3 rendered concept image(s) into explorer gallery
2026-07-02 V5 packet refresh: status line, provenance, parametric OpenSCAD master, evolution intake
    - Validator (validate_v5_packet.py --slug sheng): 0 failures before and after
    (README Status line already valid; baseline files already present).
    - Authored cad/sheng.scad: envelope-only pipe-rank master for both branches
    (traditional-side-branch half-wave, compact-control quarter-wave), lengths
    taken verbatim from each family-spec.csv predicted_L_geom_mm column. Reed
    window/tongue gap, windchest chamber, and voicing stay explicitly out of
    scope (unmeasured per cad/p0-p1-control-parameters.csv; reed gates stay
    OPEN). Render check: openscad -o /tmp/sheng-check.stl cad/sheng.scad, exit 0.
    - Gen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
    [sheng.scad, visual-output-register.csv]
